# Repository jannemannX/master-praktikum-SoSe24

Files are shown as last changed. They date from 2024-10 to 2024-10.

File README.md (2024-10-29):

# Ice Detection System using MLX90640

This project implements an ice detection system using the **MLX90640 thermal sensor** and **ESP32 microcontroller**, inside a 3D printed enclosure as a "thermal camera" (Ice Detector Device). The Ice Detector Device communicates via MQTT to transfer raw thermal data to an HTTP service which exposes the data for further use. Another HTTP service is used to detect if or how much ice is present from the thermal data. A complete ice detection process is implemented using the [Cloud Process Execution Engine](https://cpee.org) (CPEE) and can be found [here](https://cpee.org/hub/server/Teaching.dir/Prak.dir/TUM-Prak-24-SS.dir/IceDetectorDetection.xml).

Technical details and setup instructions about each part of the system can be found in the respective READMEs:
- [Ice Detector Device README](https://github.com/jannemannX/master-praktikum-SoSe24/blob/main/ice-detector/README.md)
- [Data Service README](https://github.com/jannemannX/master-praktikum-SoSe24/blob/main/data-service/README.md)
- [Prediction Service README](https://github.com/jannemannX/master-praktikum-SoSe24/blob/main/prediction-service/README.md)

**Pictures of the system:**

<div style="text-align: center;">
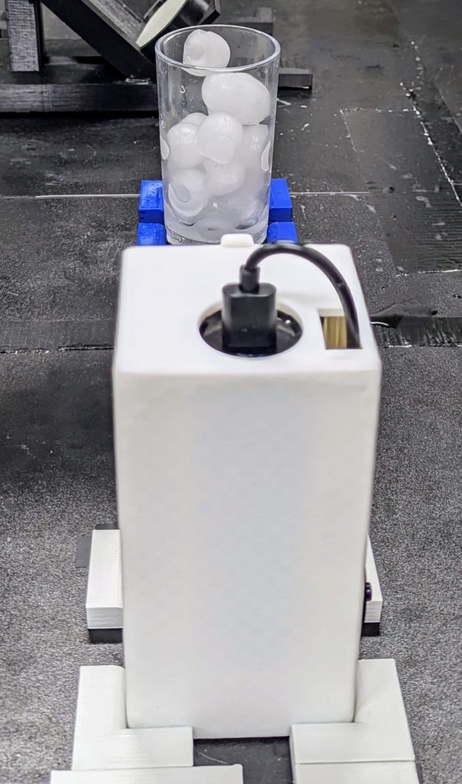
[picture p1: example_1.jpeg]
  
  <br>
  <em>Ice Detector collecting thermal data</em>
</div>
<br>
<div style="text-align: center;">
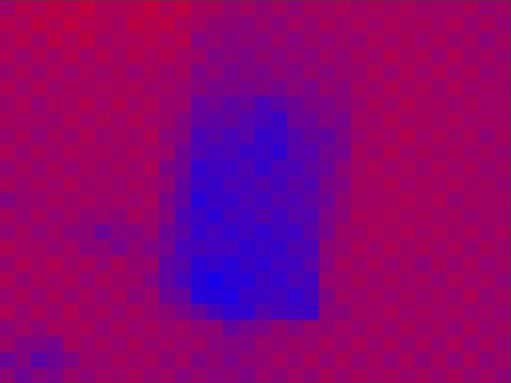
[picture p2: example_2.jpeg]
  
  <br>
  <em>Visualization of the collected data (32x24 resolution)</em>
</div>

## Architecture

We designed an architecture that allows the CPEE to interact with the Ice Detector Device in a straightforward way, while maintaining a modular design that allows for easy extension and modification of the system. The following diagram illustrates the architecture of the Ice Detection System:

```mermaid
---
title: Architecture of the Ice Detection System
---
graph TD
    subgraph Process Engine
        Process
    end
    subgraph Ice Detector Device
        MLX90640 -->|I2C| ESP32
    end
    ESP32 -->|MQTT Publish| MQTT_Broker
    subgraph Lab Machine
        Data_Service -->|MQTT Subscribe| MQTT_Broker
        Process -->|HTTP GET /temperature| Data_Service
    end
    subgraph lehre.bpm.in.tum.de
        Process -->|HTTP POST /ice| Prediction_Service
    end
```

### Ice Detector Device
The Ice Detector Device is a custom-built thermal camera using an MLX90640 thermal array and ESP32 microcontroller. It captures thermal data at 4Hz using a chess pattern sampling mode for better accuracy and stability. The device publishes both ambient temperature and a 24x32 temperature grid via MQTT, which allows for real-time updates. The complete device is housed in a custom 3D-printed enclosure designed for easy assembly and maintenance. For detailed setup and usage instructions, see the [Ice Detector Device README](https://github.com/jannemannX/master-praktikum-SoSe24/blob/main/ice-detector/README.md).

### Data Service
The Data Service acts as a bridge between the MQTT-based sensor data and HTTP clients. It subscribes to the MQTT topics where the Ice Detector Device publishes its readings and maintains the latest temperature data in memory. Through its REST API, it provides access to both the current ambient temperature and the complete temperature grid. The service includes a web-based dashboard for real-time monitoring of the thermal data. See the [Data Service README](https://github.com/jannemannX/master-praktikum-SoSe24/blob/main/data-service/README.md) for setup and API details.

### Prediction Service
The Prediction Service implements the ice detection logic by analyzing the thermal data. It accepts temperature grid data via HTTP POST requests and uses configurable thresholds to determine both the presence of ice and the percentage of the captured area that appears to be frozen. The service is designed to be simple, but effective, using temperature differences rather than absolute values for more reliable detection across varying ambient conditions. For API specifications and deployment instructions, refer to the [Prediction Service README](https://github.com/jannemannX/master-praktikum-SoSe24/blob/main/prediction-service/README.md).

## Process
The goal was to find a fun, modular and reusable way to detect if there was any or enough ice dispensed during the existing cocktail mixing process, to then use it to handle these cases. For demonstration purposes we implemented a process that utilizes both the data service as well as the prediction service to add error detection and handling to the already existing ice dispensing process.

### Ice Detection Process

Our [ice detection process](https://cpee.org/hub/server/Teaching.dir/Prak.dir/TUM-Prak-24-SS.dir/IceDetectorDetection.xml) utilizes the data and prediction service to detect the presence of ice in a glass. It is meant to be used as a subprocess by other processes to know whether any ice is present in the glass (retrieved via the result data object). For this we created a plethora of Cobot programs for the sake of modularity, which we call via the REST API provided by the Lab Machine. 

---

First we put down the glass and turn on the device by letting the robot press the button, the height of the button was carefully chosen to avoid the robot accidently pressing it while gripping the device. Then we pickup the device and move it down from the ice machine. Before directly going to the picture spot we had to change grip, due the range limit of the robot arm in combination with objects in the workspace which block free movement close to the ground.  

<div style="text-align: center;">
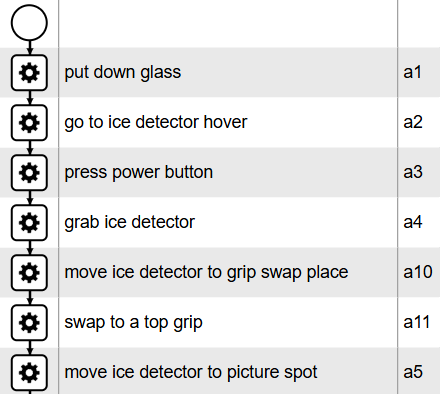
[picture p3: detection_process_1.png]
  
  <br>
  <em>Turning on the device and moving it into place in the CPEE</em>
</div>
<br>
<div style="text-align: center;">
  
  <br>
  <em>The same but in the real world (2x speed)</em>
</div>

---

In the next group of steps we perform the actual detection of ice by first waiting 5 seconds to let the image stabilize and then gathering the temperature data (temperature grid & ambient temperature) from the data service. We then send this data to the prediction service to get the result of the ice detection. The result is then stored in a data element and can be used by the parent process to decide what to do next.

<div style="text-align: center;">
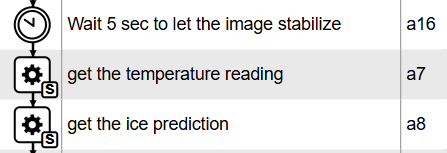
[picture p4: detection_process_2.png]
  
  <br>
  <em>Ice detection in the CPEE</em>
</div>

---

In the end we put the device back to its original position, turn it off by pressing the button again and move into the starting position above the glass to be ready for the next step in the parent process.

<div style="text-align: center;">
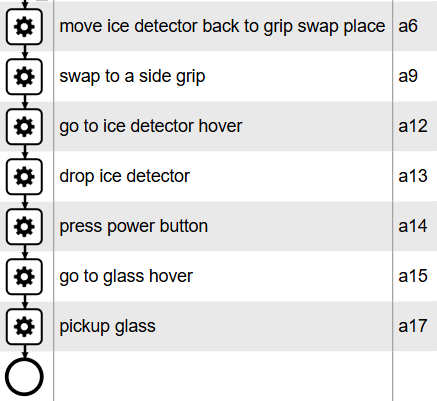
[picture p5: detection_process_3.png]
  
  <br>
  <em>Final process steps in the CPEE</em>
</div>

### Demonstration Process

Our [demonstration process](https://cpee.org/hub/server/Teaching.dir/Prak.dir/TUM-Prak-24-SS.dir/IceDetectorDemo2.xml) is a simple process that demonstrates the use of the Ice Detection System in a real-world scenario. The idea is to check if ice was dispensed during the cocktail mixing process and to handle the case where no ice was detected. We do this by calling existing Cobot programs via the REST API provided by the Lab Machine for picking up the glass. Then we use the existing [ice dispensing process](https://cpee.org/hub/server/Projects.dir/RCIS24.dir/get_ice.xml) as a subprocess. Afterwards we use our Ice Detection process to check if ice was dispensed. If no ice was detected, we retry the ice dispensing process up to the value of `max_retries` which is defined in the CPEE as a data element.

<div style="text-align: center;">
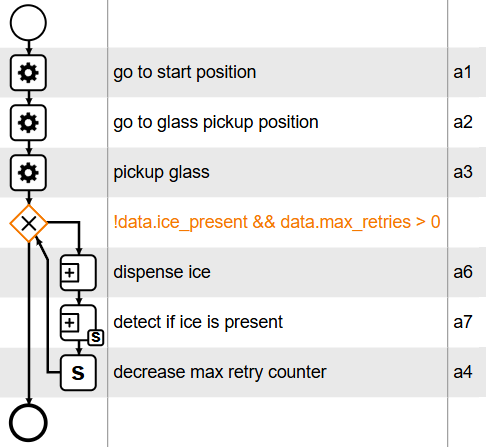
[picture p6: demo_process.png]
  
  <br>
  <em>Demonstration process in the CPEE</em>
</div>

## Challenges

### Infrared Distortion and Noise
Glass and especially plexiglass distort the infrared signal. This was a problem since we wanted to detect ice inside a plexiglass cup. The detection still works reliably as the temperature difference between ice and ambient is large enough. To further stabilize detection results however, we implemented a smoothing of the thermal data and used Chess Mode for the sensor, too avoid false positives caused by noisy readings.

### 3D Printing of Enclosure
The 3D modelling and printing was very challenging as we had no prior experience with any of this. After countless iterations and a lot of help from the internet, we finally managed to print a working enclosure for the device, that holds together via a snap-fit mechanism and does not rely on screws or glue and therefore can be easily assembled and disassembled. In the process we learned a lot about 3D modelling and printing and are now the proud owner of a BambuLab A1 Mini.

### MQTT Publish Size Limit
To reliably transmit the thermal data from the ESP32 to the Data Service, we had to split the data by the rows of the sensor and send them in multiple messages. This was necessary because the data was too large for the ESP32 to send in one message without significantly more complex communication, memory management and error handling. By publishing the data into multiple topics, we were able to keep the communication and the code simple and reliable.

## Future Work

### Ice Detection Algorithm
The current ice detection algorithm is based on a simple thresholding of the temperature data. Future work could include the implementation of a more sophisticated algorithm that takes into account the spatial distribution of the temperature data and the distance and size of the glass. This could be achieved by using machine learning techniques to train a model on a dataset of thermal images with and without ice. This was unnecessary for the current project, as the ice detection was already working reliably with the simple thresholding, but might be necessary for more complex use cases.

### Limiting Thermal Noise
Further research could be put into how to optimally shield the sensor from thermal noise. This could include modifying the enclosure to better shield the sensor from ambient temperature changes or by implementing a more sophisticated noise reduction algorithm in the software. Even with the noise we could reliably detect ice, but the system could be made more robust and less prone to fluctuation by reducing the noise.

### Integration with other Systems
As we build our system in a modular way, it is easy to integrate it with other systems. For example, it could be used to detect humans in an area without the them needing to move regularly as with a PIR sensor. The thermal camera could also be used to detect overheating in electrical systems or to detect the presence of a specific object in a room. The possibilities are countless, but applications needing more fine grained temperature data or a higher resolution would require a different (and more expensive) sensor.

## Conclusion
While the solution of building a DIY thermal camera for the task at hand might seem completely overengineered at first, it was a challenging, fun and educational project that allowed us to learn a lot about processes and process engines in a real-world scenario, thermal imaging, working with a robot arm, REST APIs, microcontroller, 3D printing and much more. The system we built is modular and can be easily extended or modified to fit other use cases. The ice detection process we implemented is simple but effective and could be used in a variety of applications. We are proud with the results achieved and are curious to see which other use cases the thermal camera might have in the future. If you have any questions or need help feel free to reach out at [jan.wesseling@tum.de](mailto:jan.wesseling@tum.de)!

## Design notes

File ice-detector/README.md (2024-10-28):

# Setup Guide
A DIY thermal imaging system that detects ice formation using an MLX90640 thermal camera and ESP32 microcontroller. The device continuously monitors surface temperatures and transmits data via MQTT for real-time ice detection. It is powered by a power bank and can be turned on and off using a physical button.

## Hardware Requirements
- ESP32 Development Board (e.g., ESP32-WROOM-32)
- MLX90640 Thermal Array
- Breakout Board for MLX90640 (EVB)
- [Anker PowerCore 5000mAh](https://www.amazon.de/dp/B01CU1EC6Y)
- [USB-Cable with power button](https://www.amazon.de/dp/B0C9PQGHGT)
- [Small flexible micro USB cable](https://www.amazon.de/dp/B071K8SW9P)
- 3D Printed Enclosure (see setup step 10)
- Jumper cables
- Recommended: Non-conductive tape

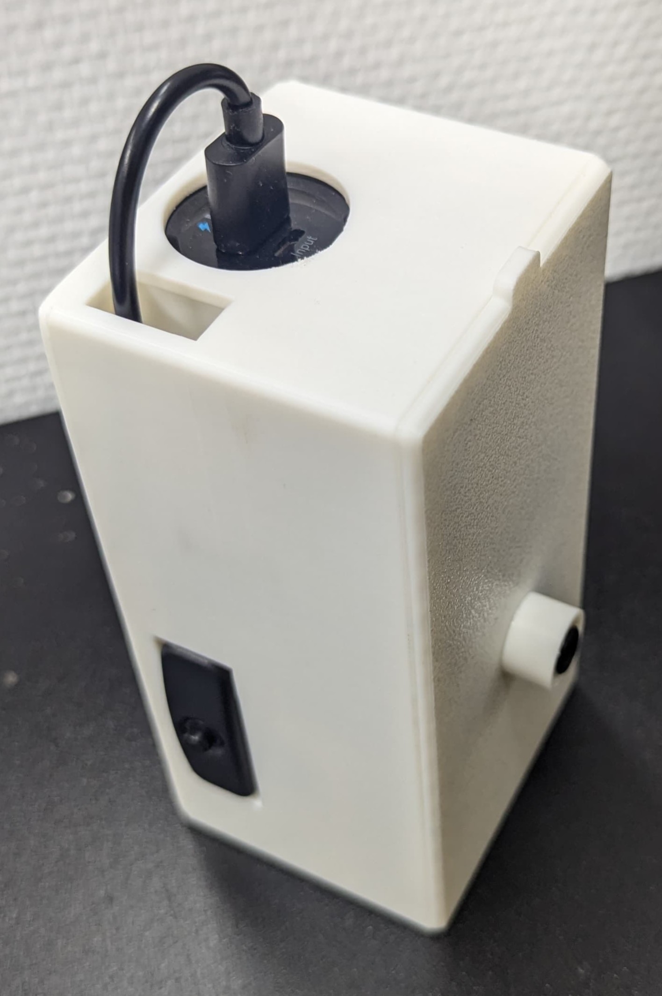
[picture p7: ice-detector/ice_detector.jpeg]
Ice Detector


## Steps

1. **Install the Arduino IDE**

   - Download and install the latest version of the Arduino IDE from the [official Arduino website](https://www.arduino.cc/en/software).

2. **Add the ESP32 Board Manager URL**

   - Open the Arduino IDE.
   - Go to **`File` > `Preferences`**.
   - In the **"Additional Boards Manager URLs"** field, enter:

     ```
     https://raw.githubusercontent.com/espressif/arduino-esp32/gh-pages/package_esp32_index.json
     ```

3. **Install the ESP32 Board Package**

   - Go to **`Tools` > `Board` > `Boards Manager`**.
   - In the search bar, type **`esp32`**.
   - Locate **"esp32 by Espressif Systems"** and click **`Install`**.

4. **Install USB Driver (if necessary)**

   - If your ESP32 board is not showing up install the driver from Silicon Labs.
   - **Download the driver here**: [Silicon Labs CP210x USB to UART Bridge VCP Drivers](https://www.silabs.com/developers/usb-to-uart-bridge-vcp-drivers).
   - Follow the installation instructions for your operating system.

5. **Select the ESP32 Board and Port**
   - In the Arduino IDE, go to Tools > Board, and select ESP32 Dev Module.
   - Go to Tools > Port, and select the port that your ESP32 is connected to.

6. **Install Required Libraries**

   - **PubSubClient Library**
     - Go to **`Sketch` > `Include Library` > `Manage Libraries`**.
     - Search for **`PubSubClient`**.
     - Install **"PubSubClient by Nick O'Leary"**.
   - **Adafruit MLX90640 Library**
     - Still in the Library Manager, search for **`Adafruit MLX90640`**.
     - Install **"Adafruit MLX90640 by Adafruit"**.
     - Install any prompted dependencies (e.g., **Adafruit BusIO**).

7. **Configure Credentials**

   - Open the `ice-detector.ino` sketch.
   - Fill in your Wi-Fi SSID, password, and MQTT server details:

     ```cpp
     const char* ssid = "YOUR_WIFI_SSID";
     const char* password = "YOUR_WIFI_PASSWORD";
     const char* mqtt_server = "YOUR_MQTT_SERVER_IP";
     ```
8. **Upload the Sketch**

   - Click the **`Upload`** button in the Arduino IDE.
   - Press and hold the boot button on the ESP32 board when the "Connecting" message appears.
   - You should be able to see output on the Serial Monitor (115200 baud rate) after the upload is complete.

9. **Connect cables**
   - Connect the MLX90640 breakout to the ESP32 (Look for the notch on the sensor and align it with the drawing on the breakout board)
   - Follow the instructions in the PDF file [PMOD_MLX90640_DS_dt.pdf](https://github.com/jannemannX/master-praktikum-SoSe24/edit/main/ice-detector/PMOD_MLX90640_DS_dt.pdf) to connect the breakout to the ESP32.
   - Connect the rest as shown below

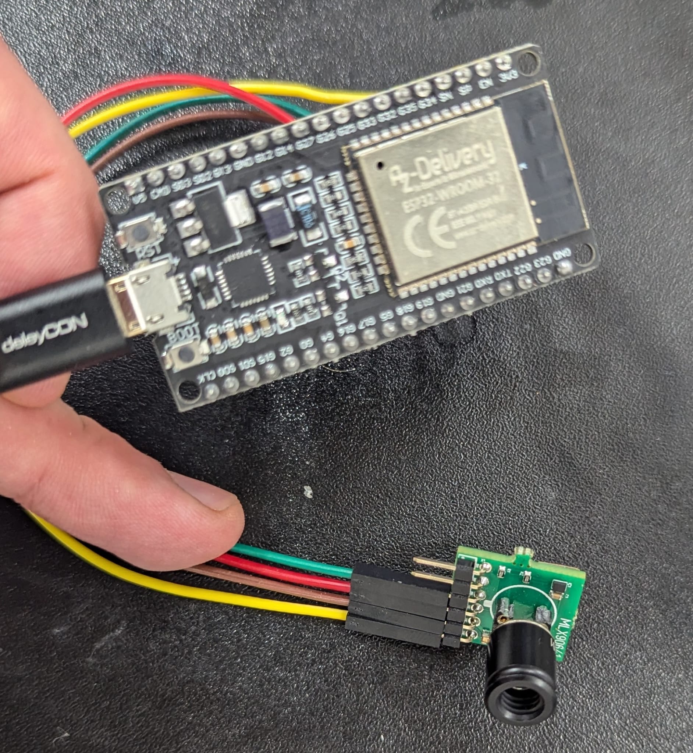
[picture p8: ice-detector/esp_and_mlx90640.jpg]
ESP and MLX90640

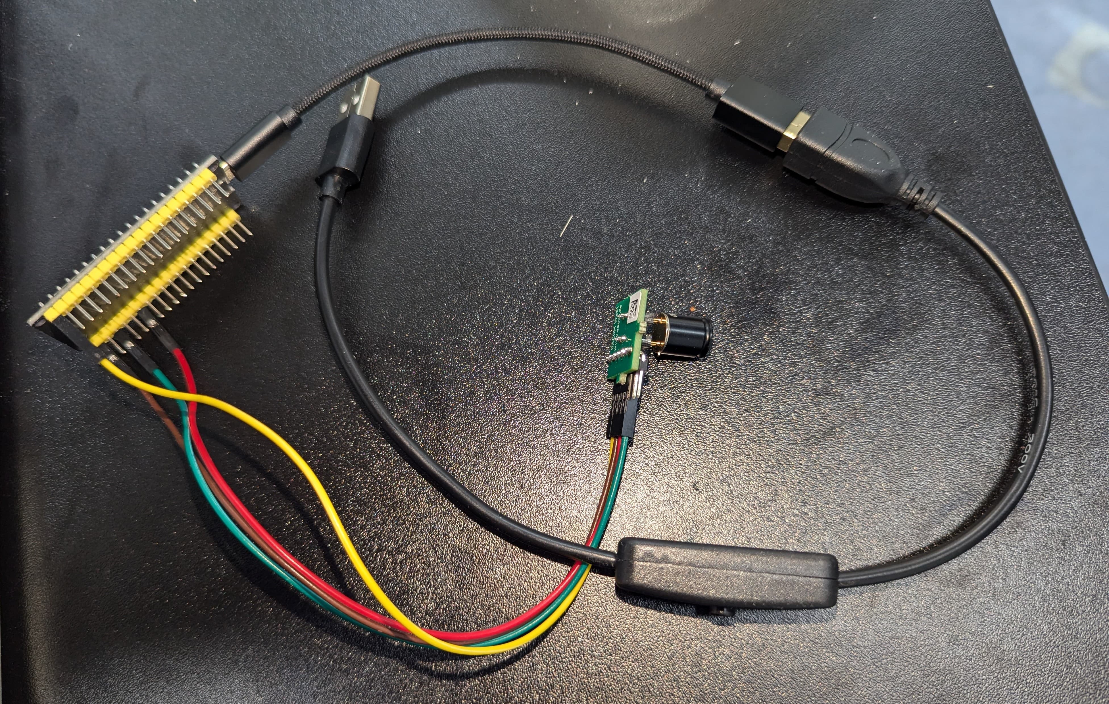
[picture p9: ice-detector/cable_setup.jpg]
Cable Setup


10.   **Print and assemble the enclosure**
   - Print the parts from the [3d_print folder](https://github.com/jannemannX/master-praktikum-SoSe24/edit/main/ice-detector/3d_print) or [Onshape](https://cad.onshape.com/documents/61ff36c19d567fb2cb1f912e/w/94b71816ca017b0d6549149e/e/821ef7029f7086ceb7cd349b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)
   - Glue the camera protection onto the lid
   - Assemble the enclosure as shown below (Use tape to fix the sensor, powerbank and button)
   - Optional: use a small esp case for better protection

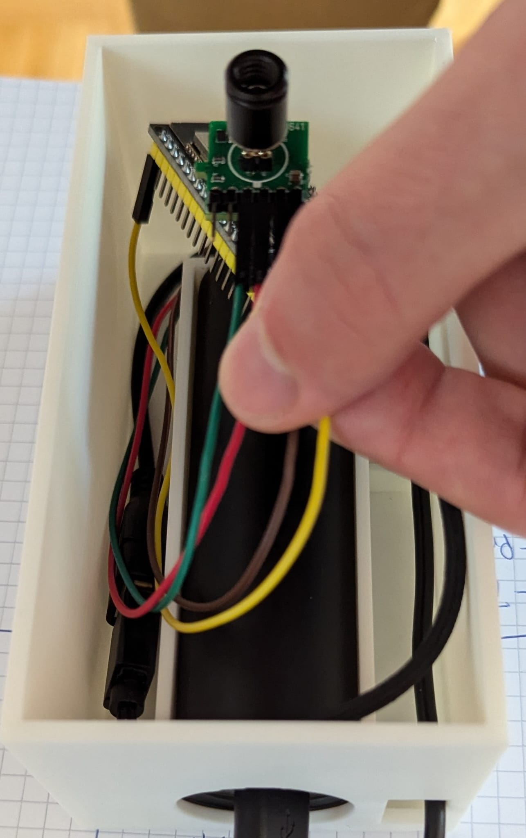
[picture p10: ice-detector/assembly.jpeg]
Assembly


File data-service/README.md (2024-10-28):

# Temperature Data Service

A microservice that collects temperature data from MQTT topics and provides it via a web API. It subscribes to ambient temperature and a grid of temperature readings topics, making this data available in JSON format and visualizing it via web dashboard.

## Deployment

1. Install dependencies:
   ```
   pip3 install -r requirements.txt
   ```

2. Set up environment:
   - Copy `.env.example` to `.env`
   - Configure these values:
     - MQTT_BROKER_IP: Your MQTT broker's IP address
     - MQTT_BROKER_PORT: Your MQTT broker's port
     - SERVICE_PORT: Port for this web service

3. Run the server:
   ```
   python3 data-service.py
   ```

## API Endpoints

### GET /temperature
Returns the current temperature readings in JSON format.

Response example (in reality the grid is 32x24):
```json
{
    "ambient_temp": 20.5,
    "grid": [
        ["19.5", "20.1", "18.9"],
        ["20.3", "19.8", "19.2"],
        ["19.7", "20.0", "19.4"]
    ]
}
```

### GET /
Serves the temperature monitoring dashboard which displays real-time sensor data with a color-coded heatmap. It shows the ambient temperature, minimum, maximum, and average temperatures, with adjustable temperature range and update interval. 

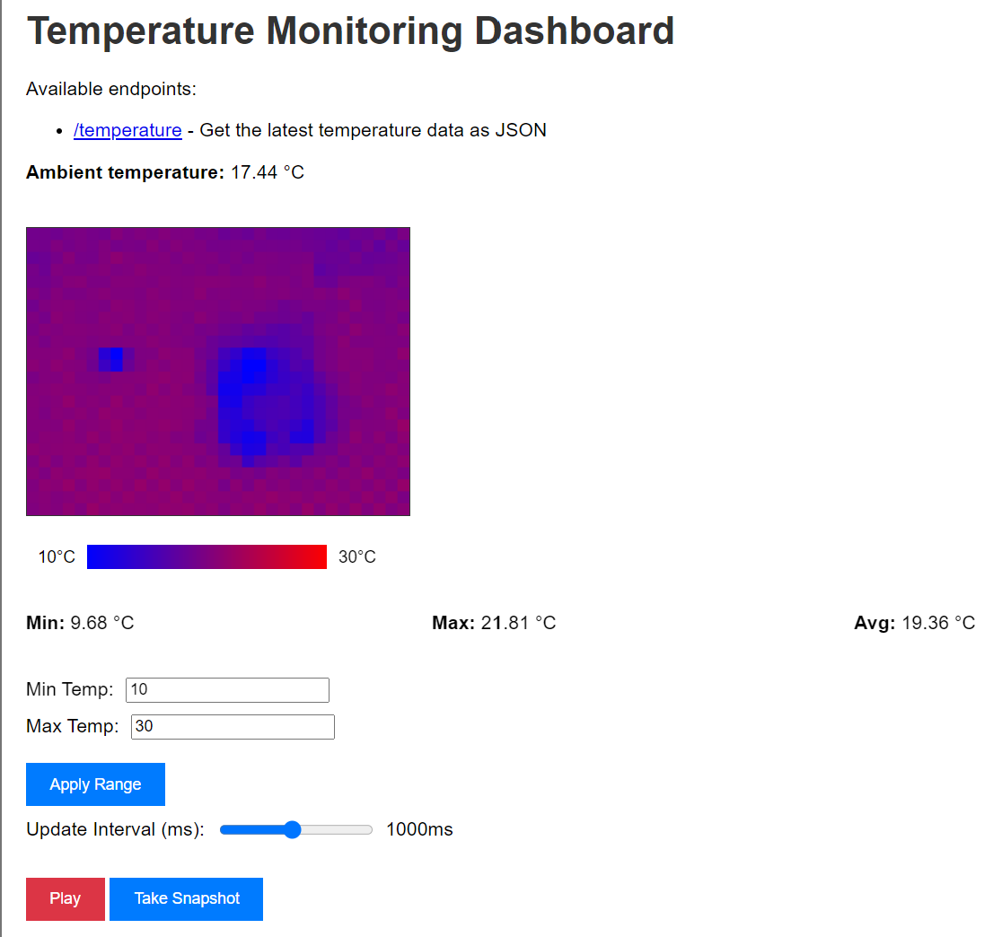
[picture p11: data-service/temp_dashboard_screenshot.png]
Temperature Dashboard Screenshot


## MQTT Topics

The service subscribes to these MQTT topics:
- `ice_detector/ambient_temp`: Ambient temperature value
- `ice_detector/temperature_grid/row#`: Temperature grid readings

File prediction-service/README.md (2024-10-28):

# Ice Detection Service

A simple microservice that analyzes temperature grid data to detect ice presence and coverage. It processes thermal sensor data by comparing temperature readings against the ambient temperature to identify cold spots that indicate the presence of ice. Can be fine-tuned by adjusting the temperature threshold and pixel threshold.

## Deployment

1. Install dependencies:
   ```
   pip3 install -r requirements.txt
   ```

2. Set up environment:
   - Copy `.env.example` to `.env`
   - Fill in the required values (primarily the service port)

3. Run the server:
   ```
   python3 prediction-service.py
   ```

## API Endpoints

### POST /ice
Determines if ice is present based on the temperature readings.

Request format:
```json
{
    "ambient_temp": 20,
    "grid": [[18, 19, 13], [17, 12, 14], [19, 18, 11]],
    "temp_threshold": 5,     // optional, default: 5
    "pixel_threshold": 0.03  // optional, default: 0.03
}
```

Response:
```json
{
    "ice_present": true
}
```

### POST /ice-percentage
Calculates the percentage of the surface area that might be covered in ice.

Request format:
```json
{
    "ambient_temp": 20,
    "grid": [[18, 19, 13], [17, 12, 14], [19, 18, 11]],
    "temp_threshold": 5  // optional, default: 5
}
```

Response:
```json
{
    "cold_pixel_percentage": 33.33
}
```

Note: The CPEE sends requests with Content-Type: application/x-www-form-urlencoded, the temperature data (JSON) must be send in a field named "data".

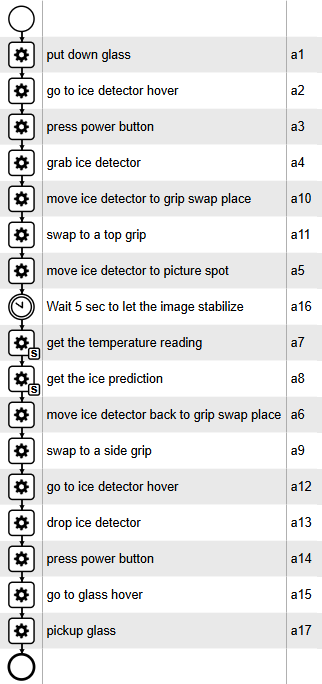
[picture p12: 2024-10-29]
detection_process.png

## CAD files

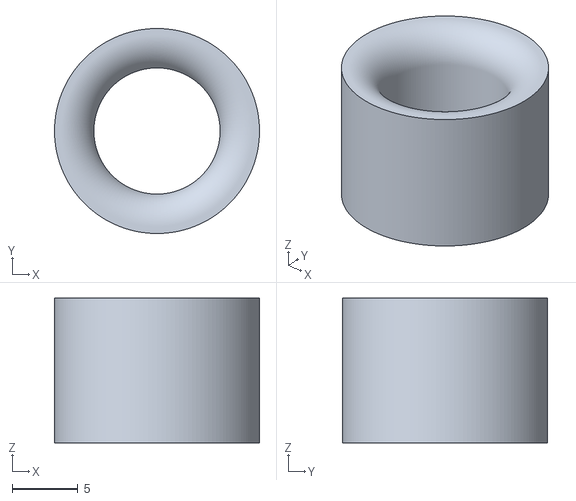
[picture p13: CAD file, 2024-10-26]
ice-detector/3d_print/Camera protection.stl
15.6 x 15.6 x 11.0

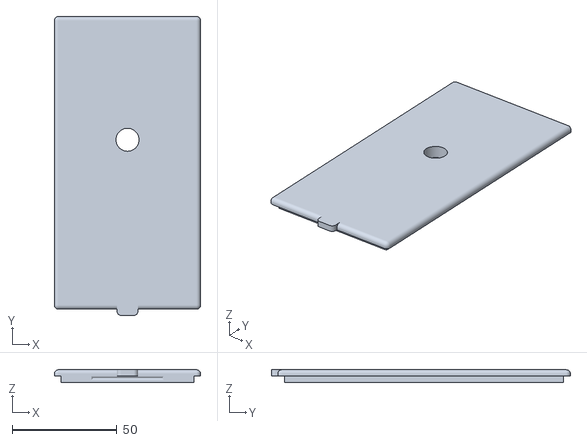
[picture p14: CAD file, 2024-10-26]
ice-detector/3d_print/Lid.stl
70.0 x 143.0 x 6.00

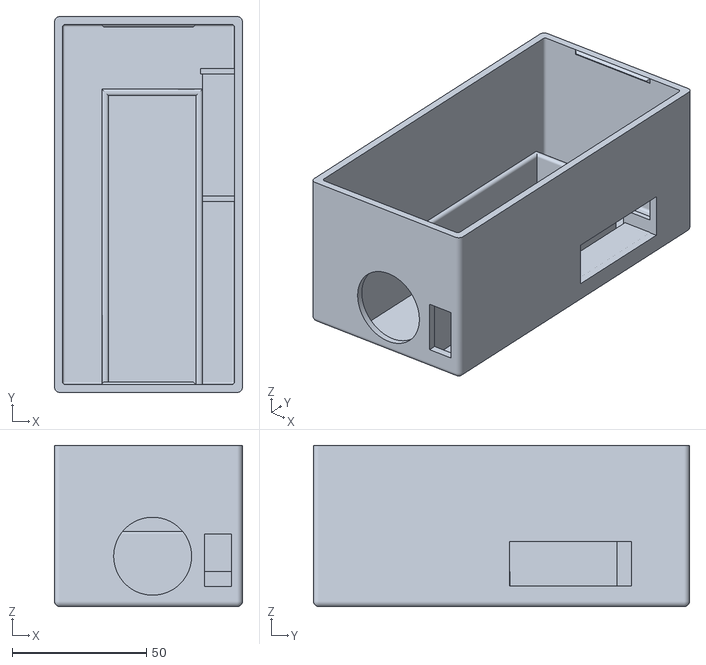
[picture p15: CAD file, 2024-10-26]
ice-detector/3d_print/Container.stl
70.0 x 140.0 x 60.0

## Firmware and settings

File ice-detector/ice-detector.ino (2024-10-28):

#include <WiFi.h>
#include <PubSubClient.h>
#include <Adafruit_MLX90640.h>

const char *ssid = "YOUR_WIFI_SSID";
const char *password = "YOUR_WIFI_PASSWORD";
const char *mqtt_server = "YOUR_MQTT_SERVER_IP";

WiFiClient espClient;
PubSubClient client(espClient);

Adafruit_MLX90640 mlx;
float frame[32 * 24];              // temperature frame buffer
unsigned long lastPublishTime = 0; // track the last publish time

void setup_wifi()
{
  delay(10);
  WiFi.begin(ssid, password);
  while (WiFi.status() != WL_CONNECTED)
  {
    delay(500);
  }
  Serial.println("WiFi connected, IP address: ");
  Serial.println(WiFi.localIP());
}

// reconnect to mqtt
void reconnect()
{
  while (!client.connected())
  {
    if (client.connect("esp32_client"))
    {
      Serial.println("mqtt connected");
    }
    else
    {
      delay(5000);
    }
  }
}

void setup()
{
  Serial.begin(115200);
  setup_wifi();
  client.setServer(mqtt_server, 1883);

  if (!mlx.begin(MLX90640_I2CADDR_DEFAULT, &Wire))
  {
    Serial.println("MLX90640 not found!");
    while (1)
      ;
  }
  mlx.setResolution(MLX90640_ADC_19BIT); // 19 bit is highest rate, lower rates might be sufficient, if power becomes a concern or i2c gets unstable
  mlx.setRefreshRate(MLX90640_4_HZ);     // at higher rates I2C might become unstable
  mlx.setMode(MLX90640_CHESS);           // chess = on every reading half the pixels are sampled, odd and even, thats why we use 4hz and publish results every 500ms.
}

void loop()
{
  if (!client.connected())
  {
    reconnect();
  }
  client.loop();

  if (millis() - lastPublishTime >= 500)
  {
    lastPublishTime = millis(); // update the last publish time

    if (mlx.getFrame(frame) != 0)
    {
      Serial.println("Failed to read frame data from MLX90640.");
      return;
    }

    float ambientTemp = mlx.getTa(false) - 8.0; // get ambient temperature, offset by -8.0°C if in free air
    String payload = String(ambientTemp, 2);

    // publish ambient temperature
    if (client.publish("ice_detector/ambient_temp", payload.c_str()))
    {
      // Serial.println("Ambient temperature published successfully");
    }
    else
    {
      Serial.println("Failed to publish ambient temperature");
    }

    // publish each row of the temperature grid
    for (uint8_t y = 0; y < 24; y++)
    {
      String rowPayload = "";
      for (uint8_t x = 0; x < 32; x++)
      {
        rowPayload += String(frame[y * 32 + x], 2);
        if (x < 31)
          rowPayload += ",";
      }

      String topic = "ice_detector/temperature_grid/row" + String(y);

      if (client.publish(topic.c_str(), rowPayload.c_str()))
      {
        // Serial.print("Row ");
        // Serial.print(y);
        // Serial.println(" published successfully.");
      }
      else
      {
        Serial.print("Failed to publish row ");
        Serial.println(y);
      }
    }
  }
}

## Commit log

2024-10-07 Added screenshot for showcasing temperature dashboard
2024-10-26 add container stl
    [Container.stl]
2024-10-26 remaining 3D files
    [Camera protection.stl, Lid.stl]
